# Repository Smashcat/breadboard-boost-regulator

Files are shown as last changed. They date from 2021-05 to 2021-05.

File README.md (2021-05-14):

# Breadboard Boost Regulator

This is a small boost regulator circuit designed for use on a breadboard. It can be fully manufacturered at JLCPCB using the gerbers.zip BOM.csv and mount.csv files. The design here produces 12.5V from 3V to 9V input. It can switch around one amp, so the output current depends on the input voltage (e.g. at 9V input, it can produce 600mA current, but at 3V input, only around 70mA due to inefficiencies). The board has 2 outputs, both the same, as the minimum board size for PCBA from JLCPCB is 20mm x 20mm, plus I just wanted two outputs :) The schematic shows the formular to change the output voltage from the default. I used 2 resistors on one side of the divider to allow more flexibility when choosing parts. I have used "basic parts" from the JLC library where possible, to reduce cost. The cost for 20 boards is currently around £26 + shipping! Obviously the cost per board reduces as the quantity increases.

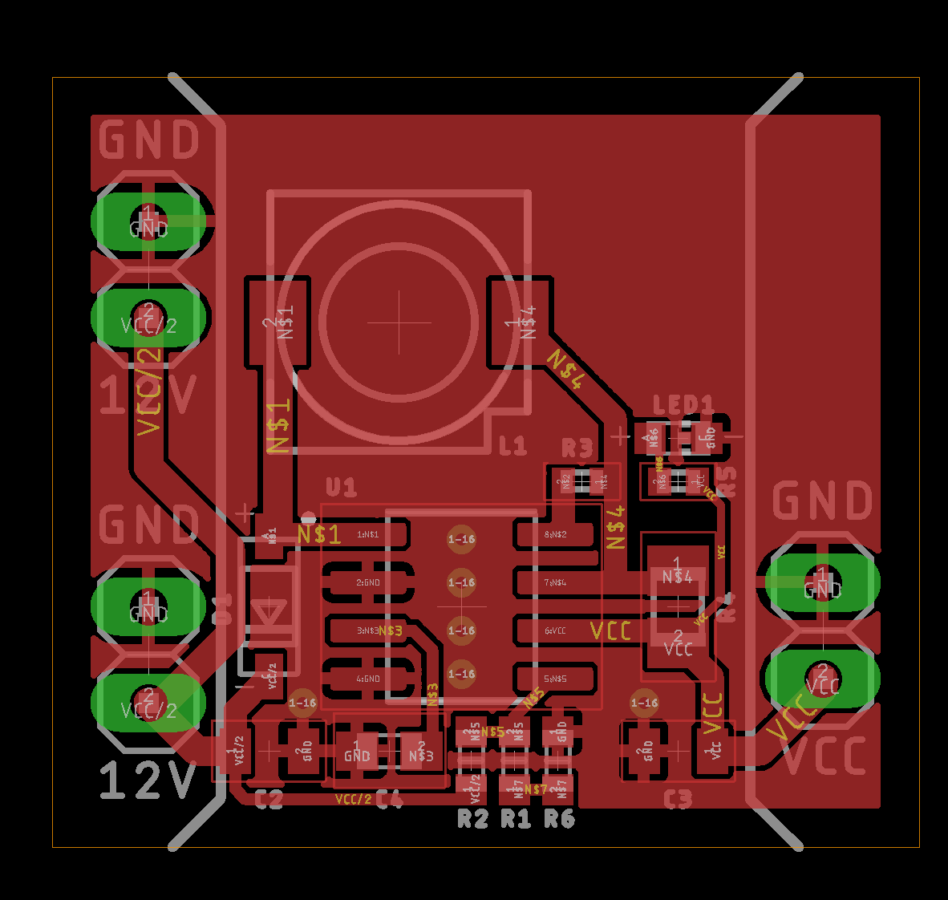
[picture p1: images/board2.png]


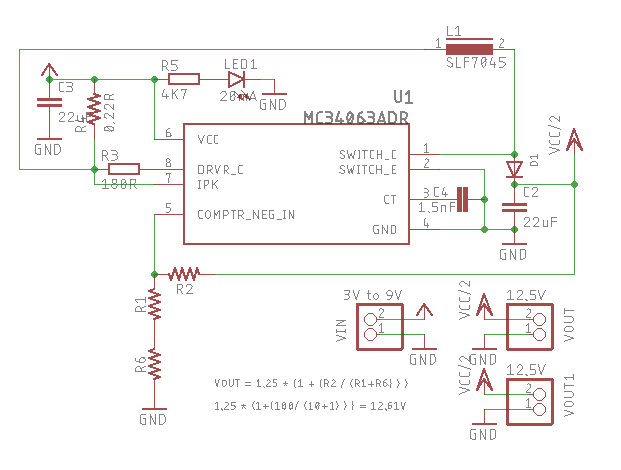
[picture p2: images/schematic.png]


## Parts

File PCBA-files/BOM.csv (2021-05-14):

Qty | Designator | Footprint | Comment | LCSC Part # | Description
1 | D1 | SOD-123 | Schottkey Diode | C8598 | SOD-123 Schottky Diode
1 | R4 | R0805 | Resistor | C25276 | 0.22ohm 0805 RESISTOR
1 | C4 | C0603 | Capacitor | C1595 | 1500pF 0603 CAPACITOR
1 | R2 | R0603 | Resistor | C25803 | 100Kohm 0603 RESISTOR
1 | R1 | R0603 | Resistor | C25804 | 10Kohm 0603 RESISTOR
1 | L1 | SMD_8.0x8.0x4.0mm | Inductor | C96966 | 150uH POWER INDUCTOR
1 | R3 | R0402 | Resistor | C25145 | 180ohm 0603 RESISTOR
1 | LED1 | LED_0603 | Chip LED | C2286 | LED
2 | C2, C3 | C0805 | Capacitor | C45783 | 22uF 0805 ceramic capacitors
1 | R5 | R0402 | Resistor | C25900 | 4.7Kohm 0402 RESISTOR
1 | U1 | SOIC-8_3.9x4.9x1.27P | Buck/Boost regulator | C32078 | 1.5-A SOIC-8 Boost/Buck/Inverting Switching Regulator
1 | R6 | R0603 | Resistor | C21190 | 1Kohm 0603 RESISTOR

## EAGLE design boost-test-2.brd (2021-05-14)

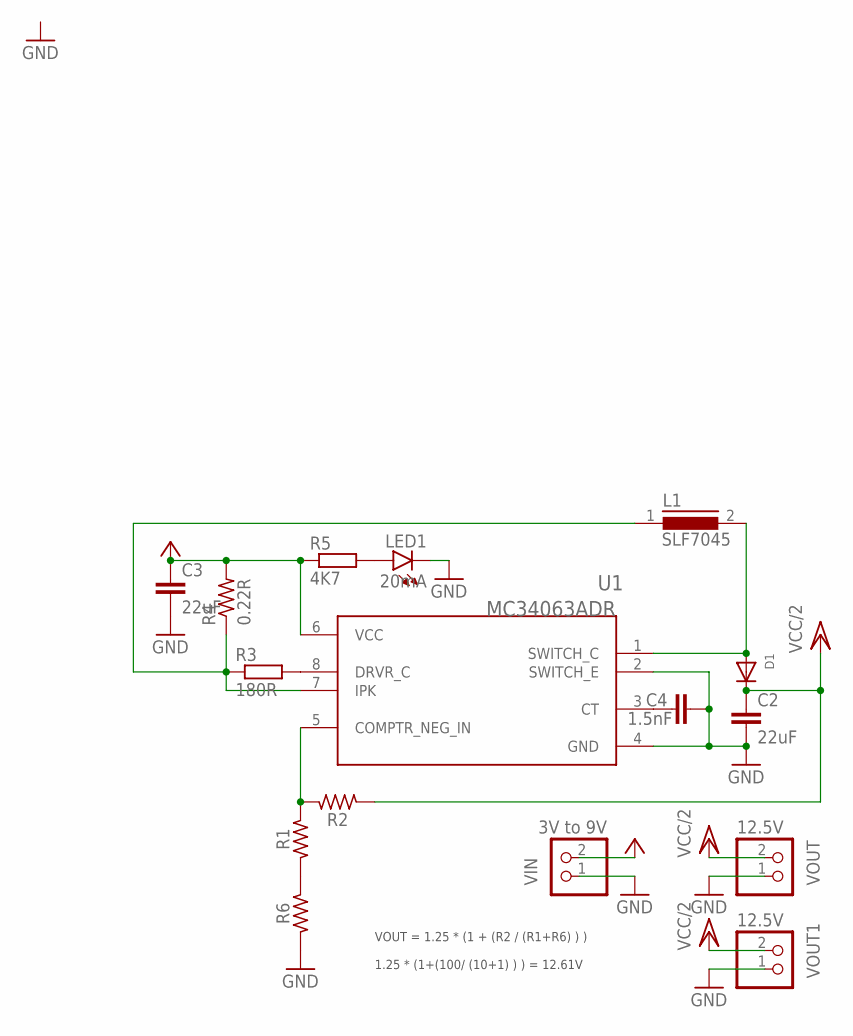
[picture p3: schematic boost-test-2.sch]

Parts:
C2, C3: 22uF; 0805
C4: 1.5nF; C0603
D1: ADAFRUIT_DIODESOD-123; ADAFRUIT_SOD-123
L1: SLF7045
LED1: 20mA; CHIP-LED0603
R1: 10K; 52101-101-REV-A_RC-MASTER-SMD_R0603MP
R2: 100K; 52101-101-REV-A_RC-MASTER-SMD_R0603MP
R3: 180R; R0402
R4: 0.22R; M0805
R5: 4K7; R0402
R6: 1K; 52101-101-REV-A_RC-MASTER-SMD_R0603MP
U1: MC34063ADR; SOIC127P599X175-8N
VIN: 3V to 9V; 1X02
VOUT, VOUT1: 12.5V; 1X02

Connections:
GND: C2.2, C3.2, C4.1, LED1.C, R6.1, U1.2 (SWITCH_E), U1.4 (GND), VIN.1, VOUT.1, VOUT1.1
unnamed: D1.A, L1.2, U1.1 (SWITCH_C)
unnamed: R3.2, U1.8 (DRVR_C)
unnamed: C4.2, U1.3 (CT)
unnamed: L1.1, R3.1, R4.1, U1.7 (IPK)
unnamed: R1.2, R2.2, U1.5 (COMPTR_NEG_IN)
unnamed: LED1.A, R5.2
unnamed: R1.1, R6.2
VCC: C3.1, R4.2, R5.1, U1.6 (VCC), VIN.2
VCC/2: C2.1, D1.C, R2.1, VOUT.2, VOUT1.2

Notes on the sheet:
VOUT = 1.25 * (1 + (R2 / (R1+R6) ) ) 1.25 * (1+(100/ (10+1) ) ) = 12.61V

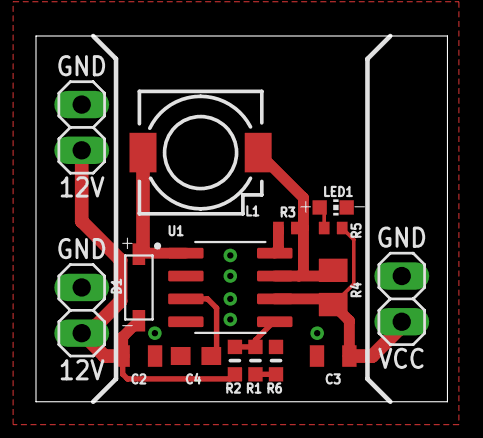
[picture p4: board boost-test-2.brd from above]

Board: 2 copper layers, 22.9 x 20.3 mm, 16 parts (0 on the bottom side), 10 nets.

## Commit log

2021-05-14 Increased size of board.png
2021-05-14 Added datasheet for boost regulator IC

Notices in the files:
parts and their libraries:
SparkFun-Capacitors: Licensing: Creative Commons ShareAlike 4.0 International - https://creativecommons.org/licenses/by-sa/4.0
